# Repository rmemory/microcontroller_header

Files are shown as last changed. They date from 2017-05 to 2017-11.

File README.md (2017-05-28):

The purpose of this project is to design a hardware (PCB) header which can be used as an interface from general I/O hardware to any uC of choice.

For example, lets say we wish to measure something (voltage, current, etc). It allows us to use any micro controller (teensy, arduino, beaglebone, etc) to interface to the measurement.

Here is the pin out. Note that it is "keyed" meaning, its designed such that the connector cannot be used with the wrong polarity.

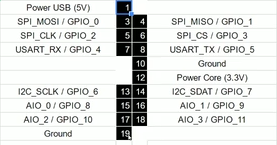
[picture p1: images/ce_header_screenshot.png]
Header screen shot


The first usage of the header will be to integrate it with the Teensy 3.2: https://www.pjrc.com/store/teensy32.html

The microcontroller header will be used as an interface to a sensor board.

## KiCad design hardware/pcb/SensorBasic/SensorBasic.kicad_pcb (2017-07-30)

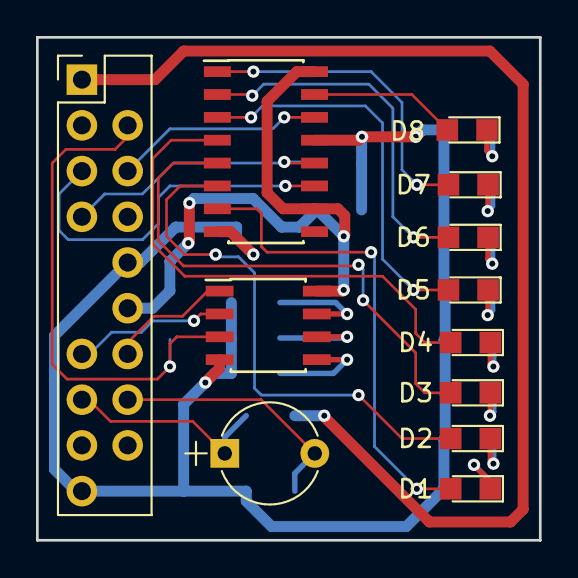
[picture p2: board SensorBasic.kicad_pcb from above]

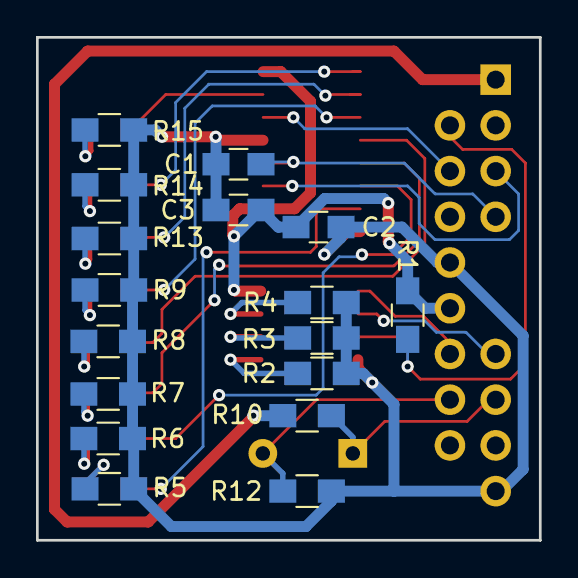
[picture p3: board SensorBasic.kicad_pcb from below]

Board: 2 copper layers, 27.9 x 27.9 mm, 29 parts (17 on the bottom side), 30 nets.

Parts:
C1, C2, C3: C; C_0805_HandSoldering
D1, D2, D3, D4, D5, D6, D7, D8: LED; LED_0805
R1, R2, R3, R4, R5, R6, R7, R8, R9, R10, R12, R13, R14, R15: R; R_0805_HandSoldering
R11: Photo Resistor; CP_Radial_Tantal_D5.5mm_P5.00mm
U1: MicroC_Header; MicroC_Header_Pitch2.54mm
U2: DS7505; SOIC-8_3.9x4.9mm_Pitch1.27mm
U3: 74HC595-PWR; SOIC-16_3.9x9.9mm_Pitch1.27mm

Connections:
/3.3V: C2.2, C3.2, R1.1, U1.12, U2.8, U3.10, U3.16
/5V: R10.1, U1.1
/OS: R1.2, U1.4, U2.3
/PR_BOT: R11.2, R12.1, U1.16
/PR_TOP: R10.2, R11.1, U1.15
/SCL: U1.13, U2.2
/SDA: U1.14, U2.1
/clockPin: U1.5, U3.11
/dataPin: U1.6, U3.14
/latchPin: C1.1, U1.7, U3.12
GND: C1.2, C2.1, C3.1, R2.2, R3.2, R4.2, R5.2, R6.2, R7.2, R8.2, R9.2, R12.2, R13.2, R14.2, R15.2, U1.10, U1.19, U2.4, U3.8, U3.13
unnamed: D1.1, R5.1
unnamed: D1.2, U3.7
unnamed: D2.1, R6.1
unnamed: D2.2, U3.6
unnamed: D3.1, R7.1
unnamed: D3.2, U3.5
unnamed: D4.1, R8.1
unnamed: D4.2, U3.4
unnamed: D5.1, R9.1
unnamed: D5.2, U3.3
unnamed: D6.1, R13.1
unnamed: D6.2, U3.2
unnamed: D7.1, R14.1
unnamed: D7.2, U3.1
unnamed: D8.1, R15.1
unnamed: D8.2, U3.15
unnamed: R2.1, U2.5
unnamed: R3.1, U2.6
unnamed: R4.1, U2.7

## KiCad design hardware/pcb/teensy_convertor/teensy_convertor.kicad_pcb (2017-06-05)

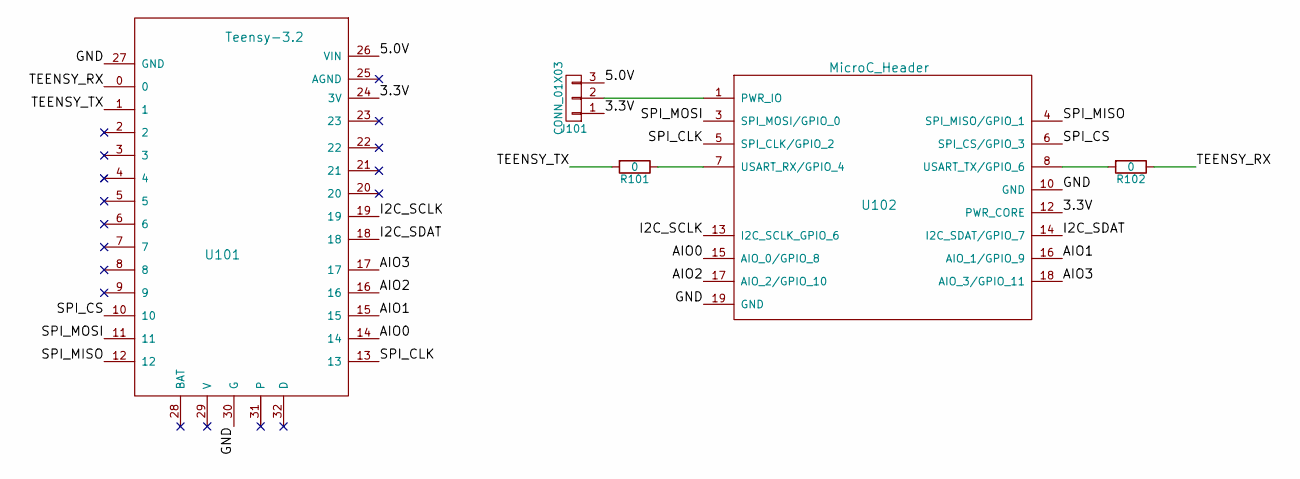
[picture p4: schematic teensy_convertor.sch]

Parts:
J101: CONN_01X03; Pin_Header_Straight_1x03_Pitch2.54mm
R101, R102: 0; R_0805_HandSoldering
U101: Teensy-3.2; Teensy-32
U102: MicroC_Header; MicroC_Header_Pitch2.54mm

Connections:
/3.3V: J101.1, U101.24 (3V), U102.12 (PWR_CORE)
/5.0V: J101.3, U101.26 (VIN)
/AIO0: U101.14, U102.15 (AIO_0/GPIO_8)
/AIO1: U101.15, U102.16 (AIO_1/GPIO_9)
/AIO2: U101.16, U102.17 (AIO_2/GPIO_10)
/AIO3: U101.17, U102.18 (AIO_3/GPIO_11)
/GND: U101.27 (GND), U101.30 (G), U102.10 (GND), U102.19 (GND)
/I2C_SCLK: U101.19, U102.13 (I2C_SCLK_GPIO_6)
/I2C_SDAT: U101.18, U102.14 (I2C_SDAT/GPIO_7)
/SPI_CLK: U101.13, U102.5 (SPI_CLK/GPIO_2)
/SPI_CS: U101.10, U102.6 (SPI_CS/GPIO_3)
/SPI_MISO: U101.12, U102.4 (SPI_MISO/GPIO_1)
/SPI_MOSI: U101.11, U102.3 (SPI_MOSI/GPIO_0)
/TEENSY_RX: R102.1, U101.0
/TEENSY_TX: R101.2, U101.1
unnamed: J101.2, U102.1 (PWR_IO)
unnamed: R101.1, U102.7 (USART_RX/GPIO_4)
unnamed: R102.2, U102.8 (USART_TX/GPIO_6)

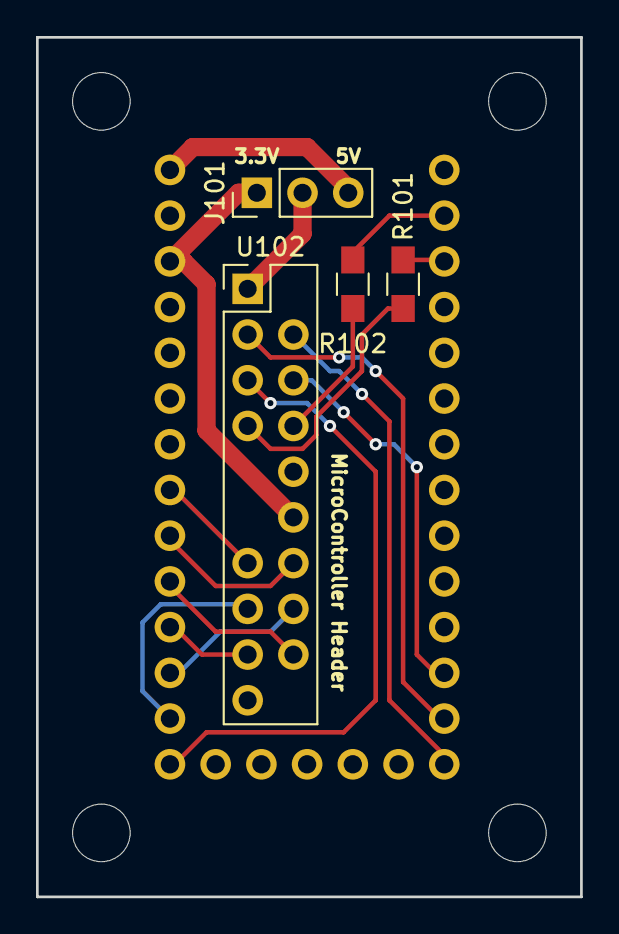
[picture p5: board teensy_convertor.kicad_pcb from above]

Board: 2 copper layers, 30.2 x 47.8 mm, 5 parts (1 on the bottom side), 18 nets.

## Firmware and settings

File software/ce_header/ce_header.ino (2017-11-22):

#define CE_spi_cs_gpio3 10
#define CE_spi_mosi_gpio0 11
#define CE_spi_miso_gpio1 12
#define CE_spi_clk_gpio2 13
#define CE_usart_tx_gpio4 1 // Teensy TX
#define CE_usart_rx_gpio5 0 // Teensy RX
#define CE_i2c_sclk_gpio6 19
#define CE_i2c_sdat_gpio7 18
#define CE_aio0_gpio8 14
#define CE_aio1_gpio9 15
#define CE_aio2_gpio10 16
#define CE_aio3_gpio11 17

/*
  Shift Register Example
 for 74HC595 shift register

 This sketch turns reads serial input and uses it to set the pins
 of a 74HC595 shift register.

 Hardware:
 * 74HC595 shift register attached to pins 8, 12, and 11 of the Arduino,
 as detailed below.
 * LEDs attached to each of the outputs of the shift register.

 Created 22 May 2009
 Created 23 Mar 2010
 by Tom Igoe

 */

/* 
 Latch = Teensy pin 0 == CE Header pin 7 == 74HC595 pin 12
Data clk = Teensy pin 13 = CE Header pin 5 == 74HC595 pin 11
Data = Teensy pin 10 = CD Header pin 6 = 74HC595 pin 14
*/

 #define latchPin CE_usart_tx_gpio4
 #define dataPin CE_spi_cs_gpio3
 #define clockPin CE_spi_clk_gpio2


void setup() {
  //set pins to output because they are addressed in the main loop
  pinMode(latchPin, OUTPUT);
  pinMode(dataPin, OUTPUT);  
  pinMode(clockPin, OUTPUT);
  Serial.begin(9600);
  Serial.println("reset");
}

void loop() {
  if (Serial.available() > 0) {
    // ASCII '0' through '9' characters are
    // represented by the values 48 through 57.
    // so if the user types a number from 0 through 9 in ASCII, 
    // you can subtract 48 to get the actual value:
    int bitToSet = Serial.read() - 48;

  // write to the shift register with the correct bit set high:
    registerWrite(bitToSet, HIGH);
  }
}

// This method sends bits to the shift register:

void registerWrite(int whichPin, int whichState) {
// the bits you want to send
  byte bitsToSend = 0;

  // turn off the output so the pins don't light up
  // while you're shifting bits:
  digitalWrite(latchPin, LOW);

  // turn on the next highest bit in bitsToSend:
  bitWrite(bitsToSend, whichPin, whichState);

  // shift the bits out:
  shiftOut(dataPin, clockPin, MSBFIRST, bitsToSend);

    // turn on the output so the LEDs can light up:
  digitalWrite(latchPin, HIGH);

}

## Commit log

2017-05-17 Add initial kicad project
    [microcontroller_header.kicad_pcb, microcontroller_header.sch]
2017-05-28 rearrange directory structure
    [microcontroller_header.kicad_pcb, microcontroller_header.sch, teensy_convertor.kicad_pcb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]
2017-05-28 Add lables from Teensy to microcontroller header
    [teensy_convertor.sch]
2017-05-28 Add a few more notes related to the Teensy 3.2
2017-05-29 Initial association and import into the layout tool
    [teensy_convertor.kicad_pcb, teensy_convertor.sch]
2017-05-29 Initial layout
    [teensy_convertor.kicad_pcb, teensy_convertor.sch]
2017-06-02 First cut of the complete layout with mounting holes
    [_saved_teensy_convertor.sch, teensy_convertor.kicad_pcb]
2017-06-04 Minor update to the schematic
    [_saved_teensy_convertor.sch, teensy_convertor.sch]
2017-06-05 final layout
    [teensy_convertor.kicad_pcb]
2017-06-05 Add gerber files, and submit to Oshpark
    [teensy_convertor-B.Cu.gbr, teensy_convertor-B.Mask.gbr, teensy_convertor-B.SilkS.gbr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]
2017-06-05 add zip file for teensy submission to oshpark, and also created a new blank project for the basic sensor board
2017-06-05 Initial SensorBasic project
    [SensorBasic.kicad_pcb, SensorBasic.sch]
2017-06-10 Initial schematic for Sensor
    [SensorBasic.sch]
2017-06-11 Add schematics symbol for temperature sensor, DS7505
    [SensorBasic.sch]
2017-06-18 Final schematic
    [SensorBasic.sch]
2017-06-19 Add footprint association and initial layout
    [SensorBasic.kicad_pcb, SensorBasic.sch]
2017-06-19 First layout with initial placements of ICs and LEDs. Still need to place the resistors, capacitors, and route traces
    [SensorBasic.kicad_pcb]
2017-06-20 First iteration of adding traces
    [SensorBasic.kicad_pcb]
2017-06-21 First version of final layout
    [SensorBasic.kicad_pcb]
2017-07-30 Added MPN part numbers to all parts except the resistors
    [SensorBasic.kicad_pcb, SensorBasic.sch]
2017-07-30 Add initial gerber and drill files
    [SensorBasic-B.Cu.gbr, SensorBasic-B.Mask.gbr, SensorBasic-B.SilkS.gbr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]
2017-07-30 add zip file containing gerbers
2017-07-30 final update of pcb file
    [SensorBasic.kicad_pcb]
